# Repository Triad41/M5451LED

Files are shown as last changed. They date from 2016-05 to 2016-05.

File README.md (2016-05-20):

# M5451LED is an Arduino Shield with an 8 digit LED display and 14 additional Outputs. It is based on the M5451 40 pin Dip IC. The IC basically works as a shift register with 35 output lines. Each line can sink about 25mA which allows it to directly drive LEDs. 21 Lines are used for the display segments and digit selection in a multiplexed fashion. The additional 14 outputs are available on a 20 postion header allowing expansion of the shield. The shield uses only 2 data lines from the arduino for (clock and data). The M5451.zip file is the Arduino libaray and 2 example programs for the shield. The first is a straight loop approach for updating the display, the second is an itnerrupt based approach for updating the display.

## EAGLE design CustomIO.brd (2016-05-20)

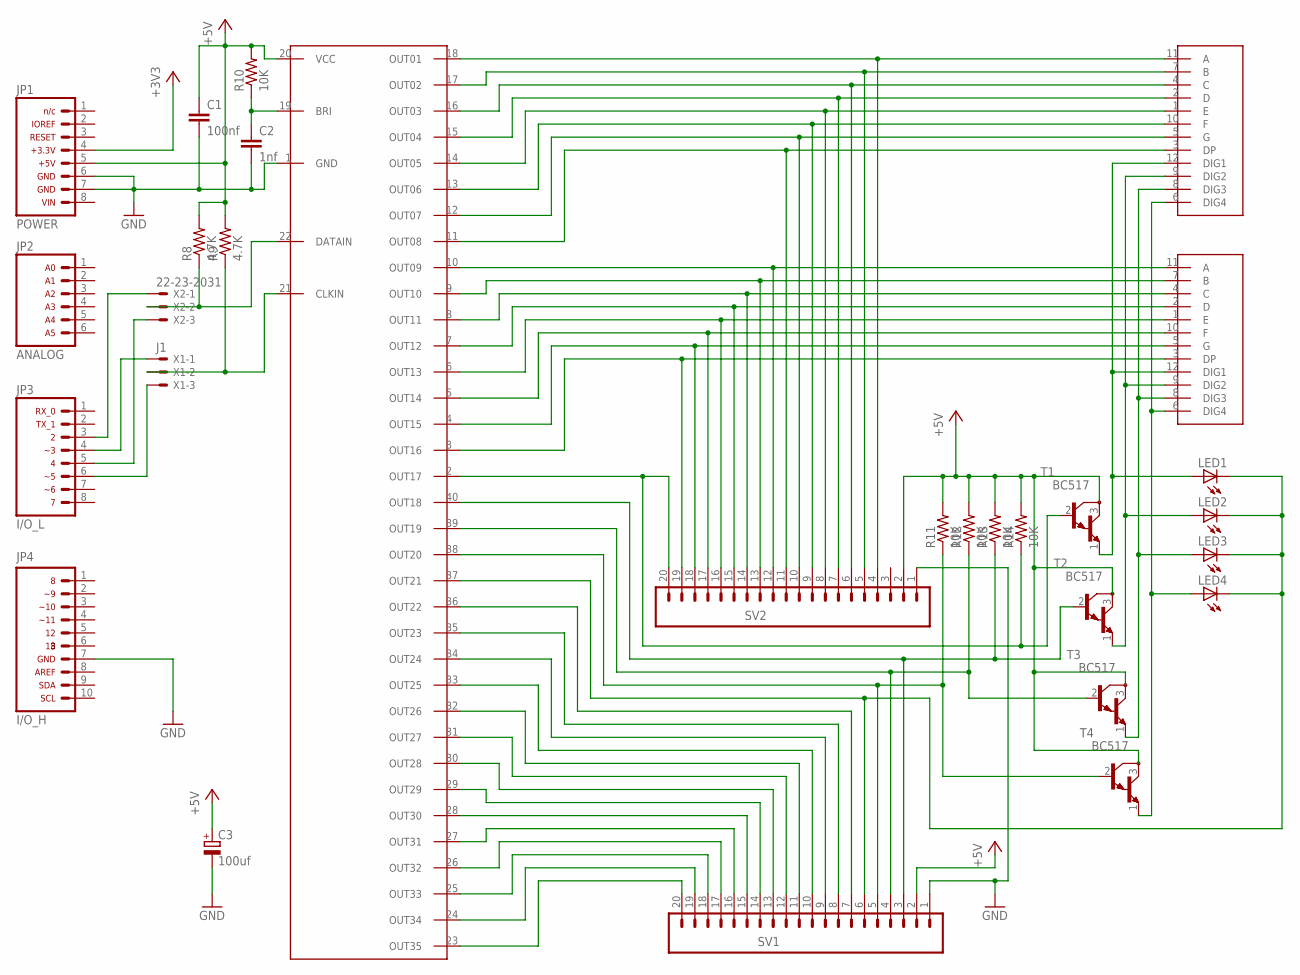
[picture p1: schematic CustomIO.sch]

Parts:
C1: 100nf; C2.5-4
C2: 1nf; C5B2.5
C3: 100uf; E2,5-7---100UF
JP1: ARDUINO_CONN-POWERSIP; CONN-1X08
JP2: ARDUINO_CONN-ANALOGSIP; CONN-1X06
JP3: ARDUINO_CONN-IO_LSIP; CONN-1X08
JP4: ARDUINO_CONN-IO_HSIP; CONN-1X10
LED1, LED2, LED3, LED4: LED3MM; HLMP-D105
R8, R9: 4.7K; AXIAL-0.3-KIT
R10, R11, R12, R13, R14: 10K; AXIAL-0.3-KIT
SV1, SV2: MA10-2
T1, T2, T3, T4: BC517; TO92
U$1: ST-M5451PDIP40; DIL40
U$2, U$3: LDS-3461BXTHURHOLE; LDS-3461BX
X1: J1; 22-23-2031
X2: 22-23-2031

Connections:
+3V3: JP1.4
+5V: C1.1, C3.+, JP1.5, R8.P$2 (2), R9.P$2 (2), R10.P$2 (2), R11.P$2 (2), R12.P$2 (2), R13.P$2 (2), R14.P$2 (2), SV1.2, SV2.2, T1.3 (C), T2.3 (C), T3.3 (C), T4.3 (C), U$1.20 (VCC)
GND: C1.2, C2.2, C3.-, JP1.6, JP1.7, JP4.7, SV1.1, SV2.1, U$1.1 (GND)
unnamed: SV2.4, U$1.18 (OUT01), U$2.11 (A)
unnamed: SV2.5, U$1.17 (OUT02), U$2.7 (B)
unnamed: SV2.6, U$1.16 (OUT03), U$2.4 (C)
unnamed: SV2.7, U$1.15 (OUT04), U$2.2 (D)
unnamed: SV2.8, U$1.14 (OUT05), U$2.1 (E)
unnamed: SV2.9, U$1.13 (OUT06), U$2.10 (F)
unnamed: SV2.10, U$1.12 (OUT07), U$2.5 (G)
unnamed: SV2.11, U$1.11 (OUT08), U$2.3 (DP)
unnamed: LED4.A, T4.1 (E), U$2.6 (DIG4), U$3.6 (DIG4)
unnamed: LED3.A, T3.1 (E), U$2.8 (DIG3), U$3.8 (DIG3)
unnamed: LED2.A, T2.1 (E), U$2.9 (DIG2), U$3.9 (DIG2)
unnamed: LED1.A, T1.1 (E), U$2.12 (DIG1), U$3.12 (DIG1)
unnamed: SV2.12, U$1.10 (OUT09), U$3.11 (A)
unnamed: SV2.13, U$1.9 (OUT10), U$3.7 (B)
unnamed: SV2.14, U$1.8 (OUT11), U$3.4 (C)
unnamed: SV2.15, U$1.7 (OUT12), U$3.2 (D)
unnamed: SV2.16, U$1.6 (OUT13), U$3.1 (E)
unnamed: SV2.17, U$1.5 (OUT14), U$3.10 (F)
unnamed: SV2.18, U$1.4 (OUT15), U$3.5 (G)
unnamed: SV2.19, U$1.3 (OUT16), U$3.3 (DP)
unnamed: SV1.20, U$1.23 (OUT35)
unnamed: SV1.19, U$1.24 (OUT34)
unnamed: SV1.18, U$1.25 (OUT33)
unnamed: SV1.17, U$1.26 (OUT32)
unnamed: SV1.16, U$1.27 (OUT31)
unnamed: SV1.15, U$1.28 (OUT30)
unnamed: SV1.14, U$1.29 (OUT29)
unnamed: SV1.13, U$1.30 (OUT28)
unnamed: SV1.12, U$1.31 (OUT27)
unnamed: SV1.11, U$1.32 (OUT26)
unnamed: SV1.10, U$1.33 (OUT25)
unnamed: SV1.9, U$1.34 (OUT24)
unnamed: SV1.8, U$1.35 (OUT23)
unnamed: SV1.7, U$1.36 (OUT22)
unnamed: LED1.K (C), LED2.K (C), LED3.K (C), LED4.K (C), SV1.6, U$1.37 (OUT21)
unnamed: R11.P$1 (1), SV1.5, T4.2 (B), U$1.38 (OUT20)
unnamed: R12.P$1 (1), SV1.4, T3.2 (B), U$1.39 (OUT19)
unnamed: R13.P$1 (1), SV1.3, T2.2 (B), U$1.40 (OUT18)
unnamed: R14.P$1 (1), SV2.20, T1.2 (B), U$1.2 (OUT17)
unnamed: R9.P$1 (1), U$1.21 (CLKIN), X1.2
unnamed: C2.1, R10.P$1 (1), U$1.19 (BRI)
unnamed: R8.P$1 (1), U$1.22 (DATAIN), X2.2
unnamed: JP3.3, X2.1
unnamed: JP3.4, X1.1
unnamed: JP3.5, X2.3
unnamed: JP3.6, X1.3

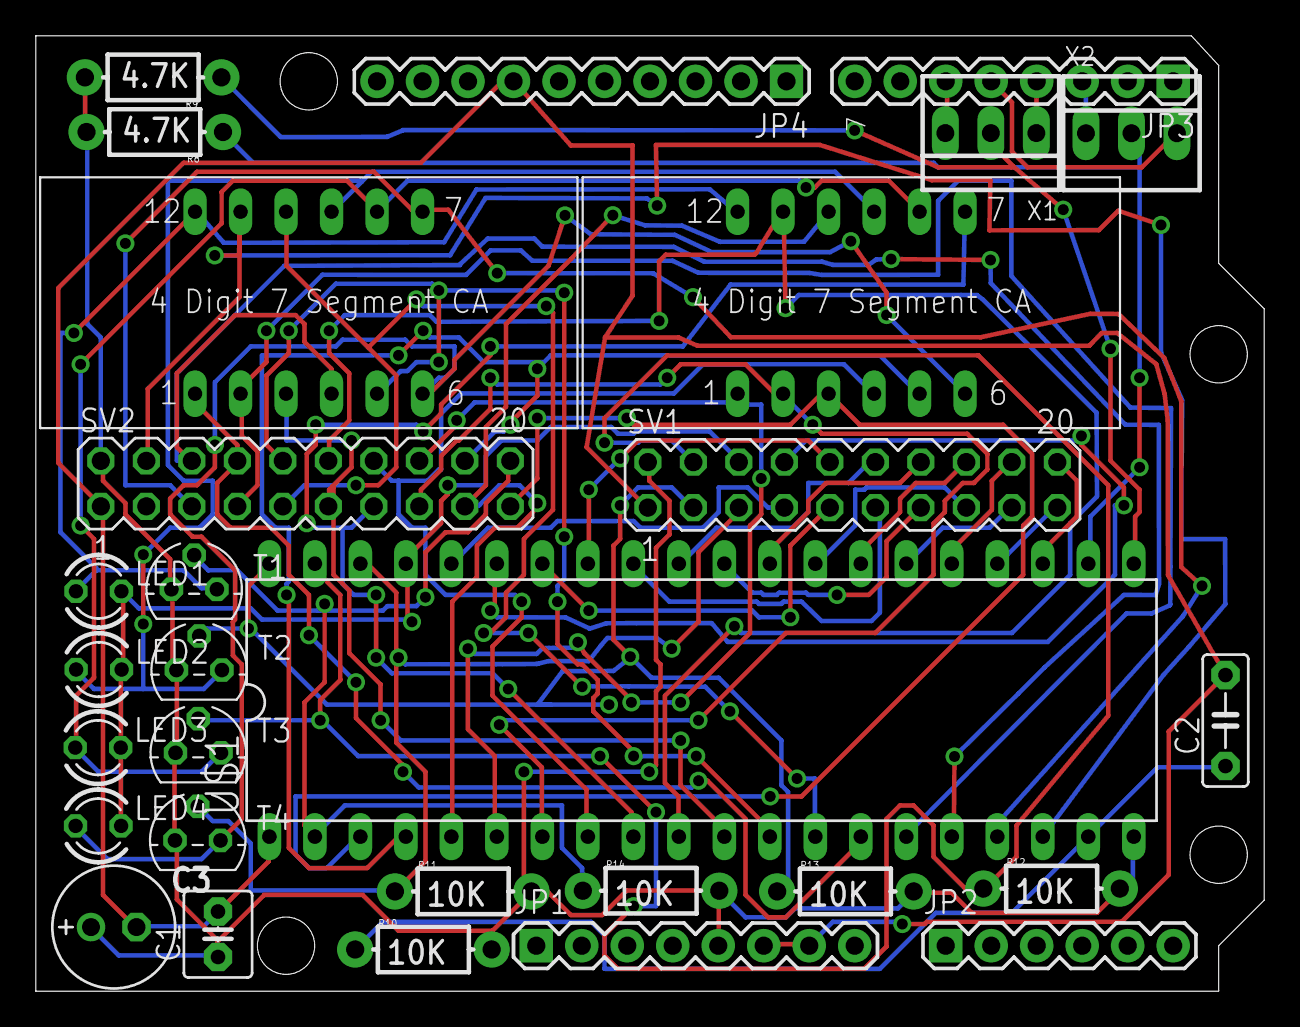
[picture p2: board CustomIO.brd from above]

Board: 2 copper layers, 68.6 x 53.3 mm, 29 parts (0 on the bottom side), 48 nets.

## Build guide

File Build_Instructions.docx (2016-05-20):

Extended I/O with 8 Digit LED Display

## Bill of Materials

C1 | 100nf (0.1 μf ) capacitor (104 marking) | 1
C2 | 1nf (0.001 μf) capacitor (102 marking) | 1
C3 | 100uf Electrolytic capacitor | 1

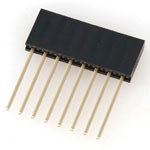
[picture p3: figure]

JP1,JP3 | 8 Position 8 x 1 .1 (2.54mm) Tall Header Arduino Connector | 2

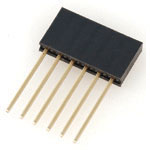
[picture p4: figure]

JP2 | 6 Position 6 x 1 .1 (2.54mm) Tall Header Arduino Connector | 1
JP4 | 10 Position 10 x 1 .1 (2.54mm) Tall Header Arduino Connector | 1

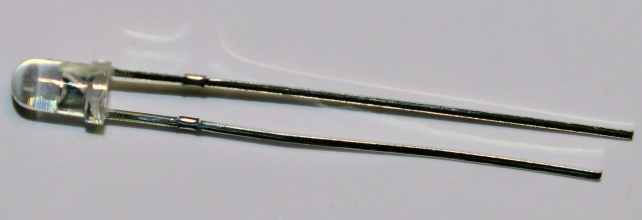
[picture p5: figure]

LED1 – LED4 | 3MM LED | 4
R8,R9 | 4.7K 1/8 W (picture for reference only) (Yellow – Violet – Red) 4 band (Yellow Violet Black Brown) 5 Band | 2
R10 – R14 | 10K 1/8 W (picture for reference only) (Brown-Black-Orange) 4 Band (Brown-Black-Black-Red)5 Band | 5
SV1-SV2 | 20 Position, 10x 2 Header | 2
T1 – T4 | 2N2907 PNP Transistor | 4
U1 | M5451 PDIP 40pin Display Controller | 1

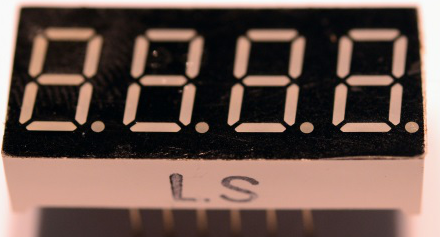
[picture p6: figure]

U2 -U3 | LDS-3461B 4 Digit 7 Segment Display | 2
X1,X2 | 3 Position x 1 Header | 2
Jumpers | 2 Position x 1 row .1 (2.54mm) Shunt | 2

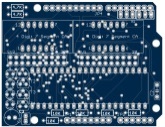
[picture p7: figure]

PCB | | 1

Schematic

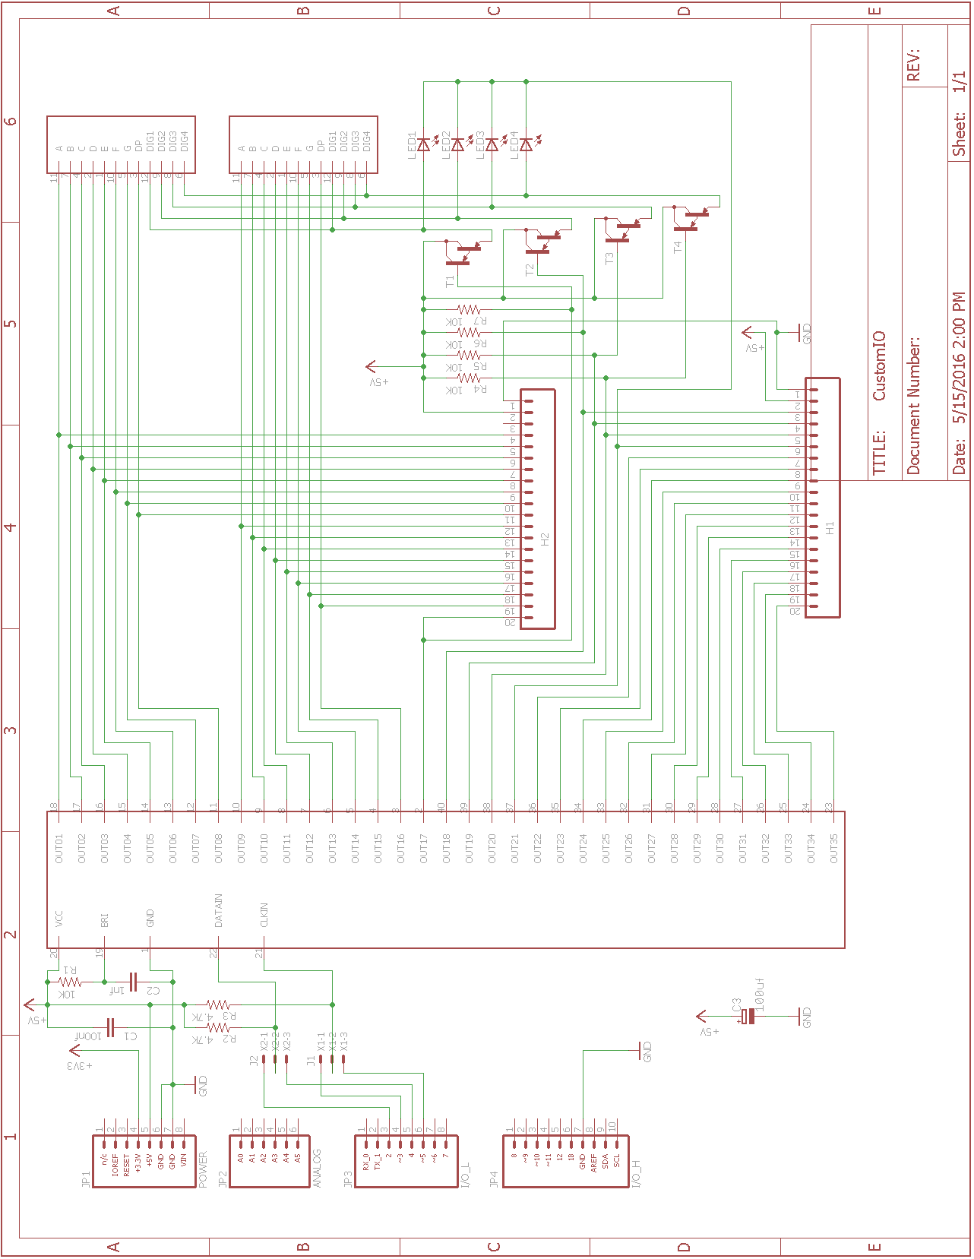
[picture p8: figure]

## Assembly

### 1 – Resistors

Solder in place the 4.7K resistors.

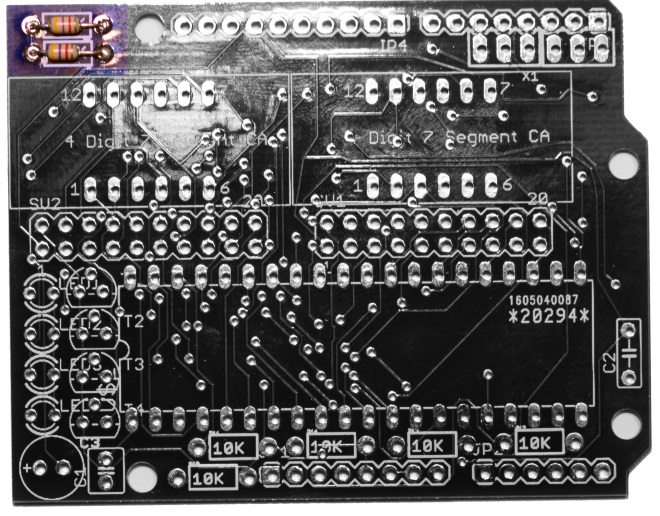
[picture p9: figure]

Solder in place the 10K resistors.

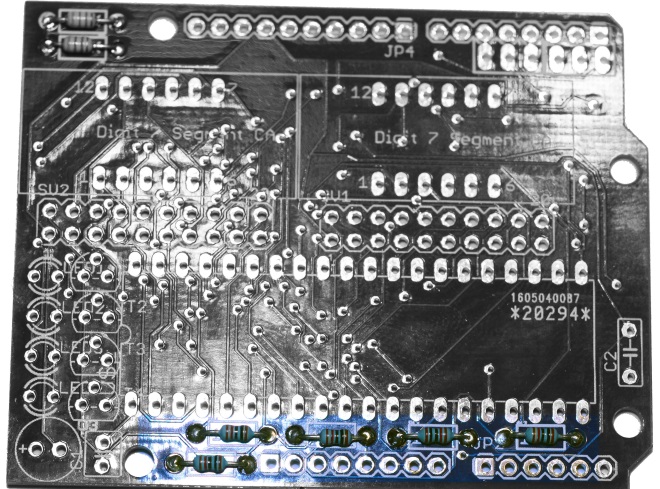
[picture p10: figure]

### 2 – Capacitors

Solder in place the 100nf (.001 μ f) Cermic Disc Capacitor.

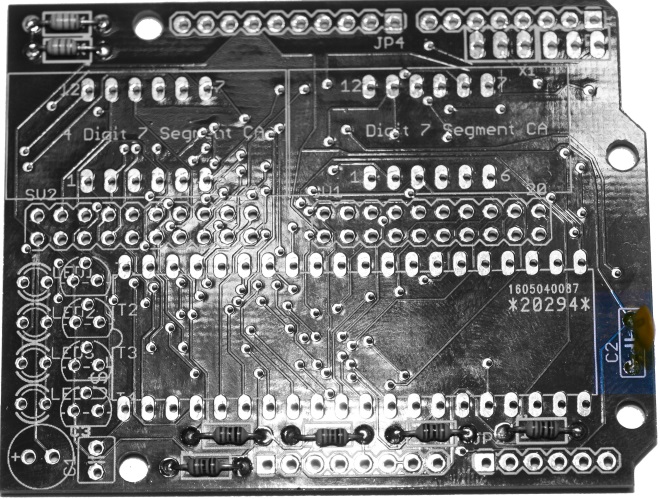
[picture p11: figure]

Solder in place the 0.1 μ f Capicator

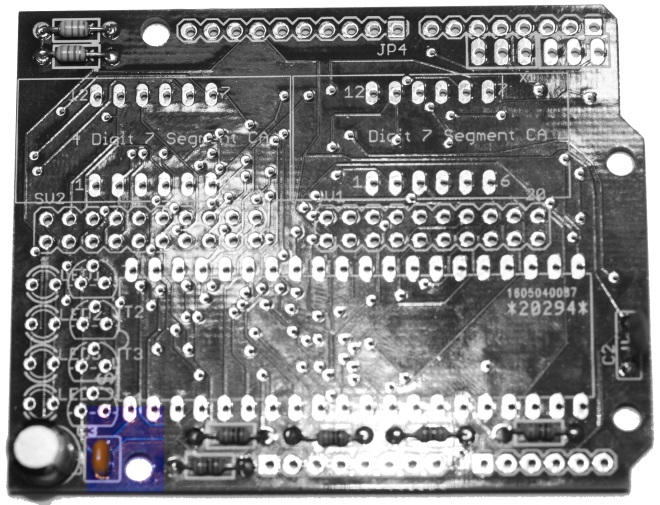
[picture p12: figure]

Solder in place the 100 μ f 6.3V Electrolytic Capacitor. It is important to note the polarity. The Capacitor is marked for the Negative lead.

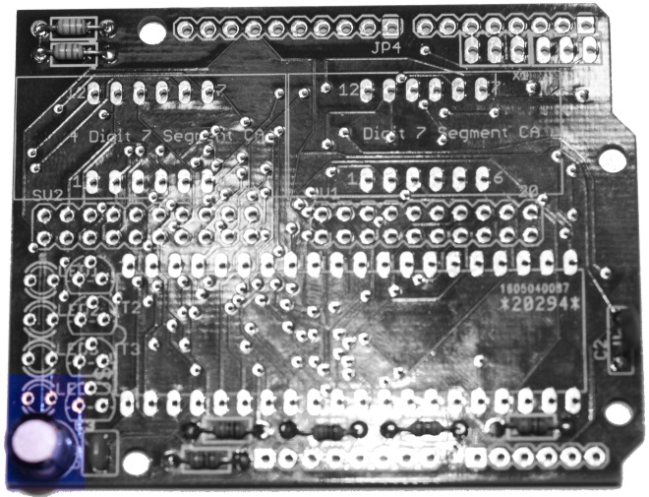
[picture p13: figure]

### 3 – Jumper and IO Headers

Solder in the 3 position by 1 row headers.

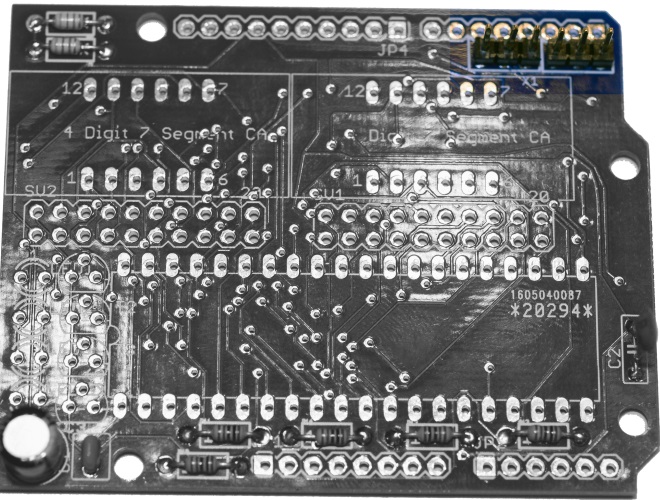
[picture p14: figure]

Solder in the 20 position (10 x2) Headers.

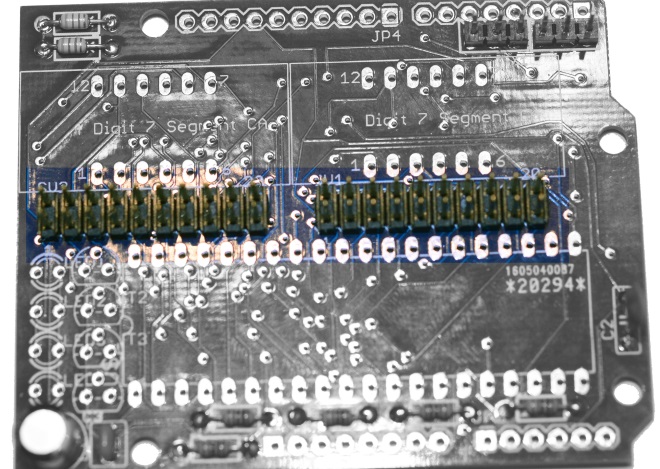
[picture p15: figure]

### 3 – LED Display and LEDS

Solder in the LED 7 Segment Displays

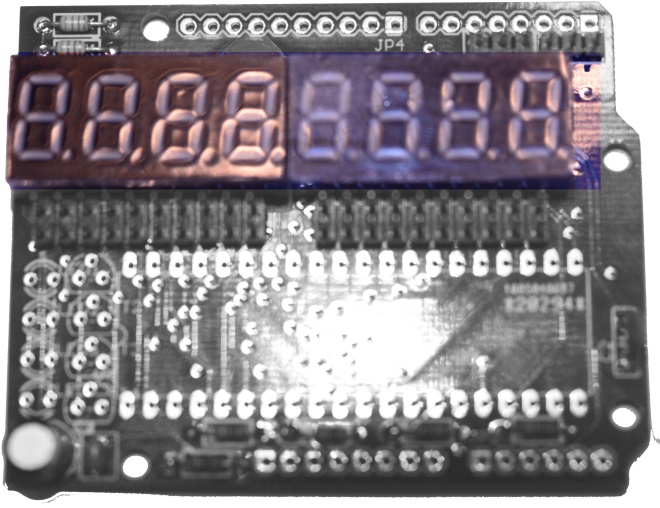
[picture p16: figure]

Solder in the LEDS. It is important to note the polarity. The Flat side is towards the middle of the board or the long lead is towards the edge of the board.

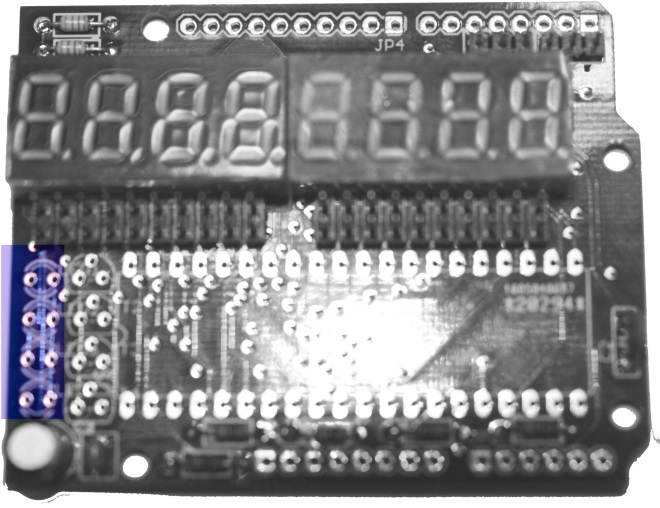
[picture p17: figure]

### 3 – Transistors

Solder in the Transistors.

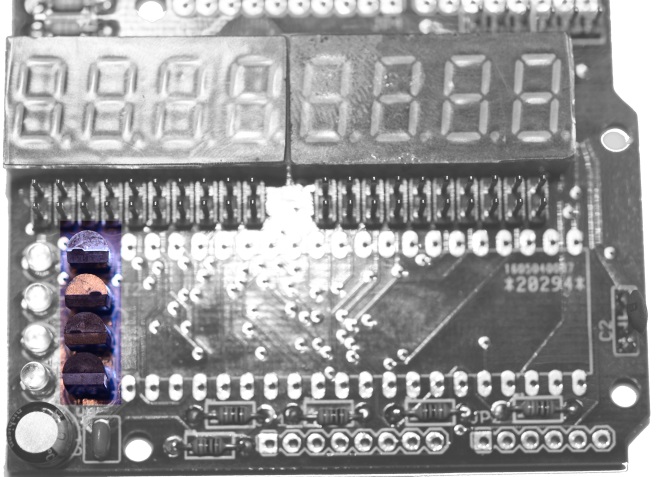
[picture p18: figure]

### 4 – IC

Solder in the IC. Pin 1 is towards the Transistors. (notch/dimple) Be careful as the pins are delicate.

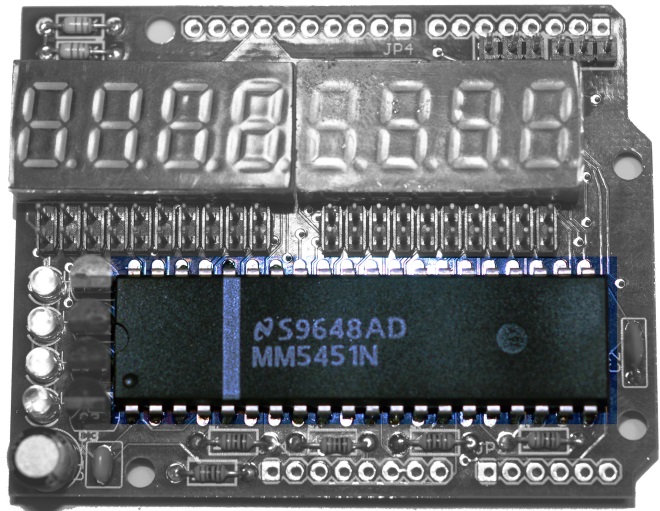
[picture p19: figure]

### 9 – Arduino Connectors

Solder in the Arduino Headers.

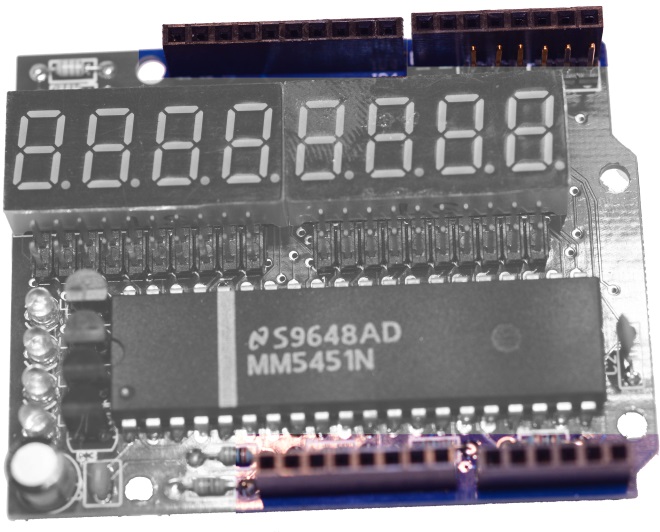
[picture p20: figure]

## Configuration

### Jumpers

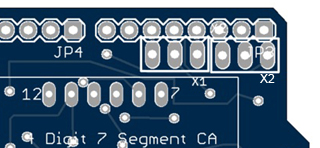
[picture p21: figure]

X1 – M5451 Clock to Arduino Data Pin Selection | Arduino Data Pin 3
X1 – M5451 Clock to Arduino Data Pin Selection | Arduino Data Pin 5
X2 – M5451 Data to Arduino Data Pin Selection | Arduino Data Pin 4
X2 – M5451 Data to Arduino Data Pin Selection | Arduino Data Pin 2

Note – For running the Sample Programs, set the Jumpers for Arduino Pins 2 and 3.

## Testing

### Sample Code

A Library is available on . It includes two example programs.

The First Example demonstrates working with the shield to update the display within the Main loop on an Arduino Sketch.

#include <M5451LED.h>

//clock pin is jumper selectable between 3 or 5

int myClockPin = 3; // Arduino pin that goes to M5451 clock

//data pin is jumper selectable between 2 or 4

int mySerDataPin = 2; // Arduino pin that goes to M5451 data

M5451 board(myClockPin,mySerDataPin);

void UpdateDisplay()

{

unsigned long int j;

for(byte dig = 0; dig < 4; dig++)

{

j = 0x00010000;

j = j << dig; //set the set of digits

j = j | ((unsigned long int)board.digitCodes[dig+4]) << 8; //shift digit segments into position

j = j | board.digitCodes[dig]; //or in other digit segments

board.setiopins(j,board.ExtendedIOPins); //load the shift register

//delay(10);

}

}

void loop() // run over and over again

{

//Sample code

//negative number check //or read a value, temp, sensor etc. upyo you

board.setNumber(102499,2);

for(int c = 0; c < 4000; c++)

{

UpdateDisplay();

}

board.BlankDisplay();

board.setNumber(-2499,2);

for(int c = 0; c < 4000; c++)

{

UpdateDisplay();

}

board.BlankDisplay();

board.setNumber(100000,2);

for(int c = 0; c < 4000; c++)

{

UpdateDisplay();

}

board.BlankDisplay();

byte dp = 0;

// count up to 499

// deminstrates changing the displayed value which is

// then displayed by the Interrupt service routine

for (unsigned long int cnt=0;cnt < 500;cnt++)

{

board.ExtendedIOPins = board.ExtendedIOPins << 1;

if ((board.ExtendedIOPins == 0x0000)||(board.ExtendedIOPins == 0x8000))

{

board.ExtendedIOPins = 0x0001;

}

board.setNumber(cnt,0); //cnt, decimal places

for(int c = 0; c < 250; c++)

{

UpdateDisplay();

}

}

//End Sample Code

//more code goes here...

}

//runs a circle around each digit (segments a,b,c,d,e,f)

//an extended IO pin is held constant while each segment is is toggled

//deminstrates segments and extended I/O updated at different timings

//the timer interrupt must be disabled while running loops

void littlechaser()

{

unsigned long int val;

board.ExtendedIOPins = 0x0001;

for(byte y = 0; y <15; y++) // outer loop is when the extended IO is updated

{

val = 0x000F0101; //All Digits ON, start with segment a

for(byte segs = 0; segs < 6; segs ++) //inner loop is when the segments are updated

{

board.setiopins(val,board.ExtendedIOPins);

val = val<<1L;

val = val & 0x0000FFFF; //keep segments

val = val | 0x000F0000; //all digits on

delay(75);

}

board.ExtendedIOPins = board.ExtendedIOPins << 1;

}

}

//runs a circle around all the digits

//extended IO pins are changed with each segment

//the timer interrupt must be disabled while running chaser

void bigchaser()

{

static const unsigned int ExtIOPattern[] = { 0xAAAA, 0x5555 };

static const unsigned int long bigchaserMap[] = {

0x00010001, // 000 00000000 00000001 00000000 00000001 // digit 1 segment a

0x00010020, // 000 00000000 00000001 00000000 00100000 // digit 1 segment f

0x00010010, // 000 00000000 00000001 00000000 00010000 // digit 1 segment e

0x00010008, // 000 00000000 00000001 00000000 00001000 // digit 1 segment d

0x00020008, // 000 00000000 00000010 00000000 00001000 // digit 2 segment d

0x00040008, // 000 00000000 00000100 00000000 00001000 // digit 3 segment d

0x00080008, // 000 00000000 00001000 00000000 00001000 // digit 4 segment d

0x00010800, // 000 00000000 00000001 00001000 00000000 // digit 5 segment d

0x00020800, // 000 00000000 00000010 00001000 00000000 // digit 6 segment d

0x00040800, // 000 00000000 00000100 00001000 00000000 // digit 7 segment d

0x00080800, // 000 00000000 00001000 00001000 00000000 // digit 8 segment d

0x00080400, // 000 00000000 00001000 00000100 00000000 // digit 8 segment c

0x00080200, // 000 00000000 00001000 00000010 00000000 // digit 8 segment b

0x00080100, // 000 00000000 00001000 00000001 00000000 // digit 8 segment a

0x00040100, // 000 00000000 00000100 00000001 00000000 // digit 7 segment a

0x00020100, // 000 00000000 00000010 00000001 00000000 // dugit 6 segment a

0x00010100, // 000 00000000 00000001 00000001 00000000 // digit 5 segment a

0x00080001, // 000 00000000 00001000 00000000 00000001 // digit 4 segment a

0x00040001, // 000 00000000 00000100 00000000 00000001 // dugit 3 segment a

0x00020001};// 000 00000000 00000010 00000000 00000001 // digit 2 segment a

byte co, c = 0;

for (co=0;co < 6;co++)

{

for(c = 0; c< 20;c++)

{

board.setiopins(bigchaserMap[c],ExtIOPattern[c & 0x01]);

delay(75);

}

}

for (co=0;co < 6;co++)

{

for(c = 20; c>0;c--)

{

board.setiopins(bigchaserMap[c-1],ExtIOPattern[(c-1) & 0x01]);

delay(75);

}

}

}

void chkLEDS()

{

unsigned long int j;

for (byte c = 0; c < 5; c++)

{

j = 0x00110000;

board.setiopins(j,0);

delay(75);

j = 0x00120000;

board.setiopins(j,0);

delay(75);

j = 0x00140000;

board.setiopins(j,0);

delay(75);

j = 0x00180000;

board.setiopins(j,0);

delay(75);

}

}

void setup() // run once, when the sketch starts

{

littlechaser();

bigchaser();

chkLEDS();

}

The second example demonstrates using an Interrupt Service Routine to update the display.

#include <TimerOne.h>

#include <M5451LED.h>

//clock pin is jumper selectable between 3 or 5

int myClockPin = 3; // Arduino pin that goes to M5451 clock

//data pin is jumper selectable between 2 or 4

int mySerDataPin = 2; // Arduino pin that goes to M5451 data

M5451 board(myClockPin,mySerDataPin);

// Every 20mS the values in the DigitCodes array and

// The values in the ExtendedIPPins are written out

void timerIsr()

{

unsigned long int j;

for(byte dig = 0; dig < 4; dig++)

{

j = 0x00010000;

j = j << dig; //set the set of digits

j = j | ((unsigned long int)board.digitCodes[dig+4]) << 8; //shift digit segments into position

j = j | board.digitCodes[dig]; //or in other digit segments

board.setiopins(j,board.ExtendedIOPins); //load the shift register

//delay(10);

}

}

void loop() // run over and over again

{

//Sample code

//negative number check

board.setNumber(102499,2);

delay(750);

board.setNumber(-2499,2);

delay(750);

board.setNumber(100000,2);

delay(750);

board.BlankDisplay();

delay(1);

byte dp = 0;

// count up to 499

// deminstrates changing the displayed value which is

// then displayed by the Interrupt service routine

for (unsigned long int cnt=0;cnt < 500;cnt++)

{

board.ExtendedIOPins = board.ExtendedIOPins << 1;

if ((board.ExtendedIOPins == 0x0000)||(board.ExtendedIOPins == 0x8000))

{

board.ExtendedIOPins = 0x0001;

}

board.setNumber(cnt,0); //cnt, decimal places

delay(150);

}

//End Sample Code

//more code goes here...

}

//runs a circle around each digit (segments a,b,c,d,e,f)

//an extended IO pin is held constant while each segment is is toggled

//deminstrates segments and extended I/O updated at different timings

void littlechaser()

{

unsigned long int val;

board.ExtendedIOPins = 0x0001;

for(byte y = 0; y <15; y++) // outer loop is when the extended IO is updated

{

val = 0x000F0101; //All Digits ON, start with segment a

for(byte segs = 0; segs < 6; segs ++) //inner loop is when the segments are updated

{

board.setiopins(val,board.ExtendedIOPins);

val = val<<1L;

val = val & 0x0000FFFF; //keep segments

val = val | 0x000F0000; //all digits on

delay(75);

}

board.ExtendedIOPins = board.ExtendedIOPins << 1;

}

}

//runs a circle around all the digits

//extended IO pins are changed with each segment

void bigchaser()

{

static const unsigned int ExtIOPattern[] = { 0xAAAA, 0x5555 };

static const unsigned int long bigchaserMap[] = {

0x00010001, // 000 00000000 00000001 00000000 00000001 // digit 1 segment a

0x00010020, // 000 00000000 00000001 00000000 00100000 // digit 1 segment f

0x00010010, // 000 00000000 00000001 00000000 00010000 // digit 1 segment e

0x00010008, // 000 00000000 00000001 00000000 00001000 // digit 1 segment d

0x00020008, // 000 00000000 00000010 00000000 00001000 // digit 2 segment d

0x00040008, // 000 00000000 00000100 00000000 00001000 // digit 3 segment d

0x00080008, // 000 00000000 00001000 00000000 00001000 // digit 4 segment d

0x00010800, // 000 00000000 00000001 00001000 00000000 // digit 5 segment d

0x00020800, // 000 00000000 00000010 00001000 00000000 // digit 6 segment d

0x00040800, // 000 00000000 00000100 00001000 00000000 // digit 7 segment d

0x00080800, // 000 00000000 00001000 00001000 00000000 // digit 8 segment d

0x00080400, // 000 00000000 00001000 00000100 00000000 // digit 8 segment c

0x00080200, // 000 00000000 00001000 00000010 00000000 // digit 8 segment b

0x00080100, // 000 00000000 00001000 00000001 00000000 // digit 8 segment a

0x00040100, // 000 00000000 00000100 00000001 00000000 // digit 7 segment a

0x00020100, // 000 00000000 00000010 00000001 00000000 // dugit 6 segment a

0x00010100, // 000 00000000 00000001 00000001 00000000 // digit 5 segment a

0x00080001, // 000 00000000 00001000 00000000 00000001 // digit 4 segment a

0x00040001, // 000 00000000 00000100 00000000 00000001 // dugit 3 segment a

0x00020001};// 000 00000000 00000010 00000000 00000001 // digit 2 segment a

byte co, c = 0;

for (co=0;co < 6;co++)

{

for(c = 0; c< 20;c++)

{

board.setiopins(bigchaserMap[c],ExtIOPattern[c & 0x01]);

delay(75);

}

}

for (co=0;co < 6;co++)

{

for(c = 20; c>0;c--)

{

board.setiopins(bigchaserMap[c-1],ExtIOPattern[(c-1) & 0x01]);

delay(75);

}

}

}

void chkLEDS()

{

unsigned long int j;

for (byte c = 0; c < 5; c++)

{

j = 0x00110000;

board.setiopins(j,0);

delay(75);

j = 0x00120000;

board.setiopins(j,0);

delay(75);

j = 0x00140000;

board.setiopins(j,0);

delay(75);

j = 0x00180000;

board.setiopins(j,0);

delay(75);

}

}

void setup() // run once, when the sketch starts

{

littlechaser();

bigchaser();

chkLEDS();

Timer1.initialize(300); //play with this value for more or less updates

Timer1.attachInterrupt( timerIsr );

}

Video’s of the running examples can be found at

https://youtu.be/1ersXG6CpGg

and

https://youtu.be/Mj3757OHWhI

### M5451LED Library

The library serves two main purposes.

- It contains the Code to shift out the data to the M5451 Chip.
- It contains the Code to convert a given number into the data needed to display the correct segments on the display.

## Programming

### I/O information

The M5451 has 35 I/O Lines, within the sample program they are mapped into an unsigned Long int and an unsigned int. This allows separate control of the display and the extended I/O.

Unsigned Long int

0000 0000 0000 0000 0000 0000 0000 0000

|||| |||| |||| |||| |||| |||| |||| |||--> Segment A 1 Output 1(pin 18)

|||| |||| |||| |||| |||| |||| |||| ||---> Segment B 1 Output 2(pin 17)

|||| |||| |||| |||| |||| |||| |||| |----> Segment C 1 Output 3(pin 16)

|||| |||| |||| |||| |||| |||| |||| -----> Segment D 1 Output 4(pin 15)

|||| |||| |||| |||| |||| |||| |||-------> Segment E 1 Output 5(pin 14)

|||| |||| |||| |||| |||| |||| ||--------> Segment F 1 Output 6(pin 13)

|||| |||| |||| |||| |||| |||| |---------> Segment G 1 Output 7(pin 12)

|||| |||| |||| |||| |||| |||| ----------> DP 1 Output 8(pin 11)

|||| |||| |||| |||| |||| |||------------> Segment A 2 Output 9(pin 10)

|||| |||| |||| |||| |||| ||-------------> Segment B 2 Output 10(pin 9)

|||| |||| |||| |||| |||| |--------------> Segment C 2 Output 11(pin 8)

|||| |||| |||| |||| |||| ---------------> Segment D 2 Output 12(pin 7)

|||| |||| |||| |||| |||-----------------> Segment E 2 Output 13(pin 6)

|||| |||| |||| |||| ||------------------> Segment F 2 Output 14(pin 5)

|||| |||| |||| |||| |-------------------> Segment G 2 Output 15(pin 4)

|||| |||| |||| |||| --------------------> DP 2 Output 16(pin 3)

|||| |||| |||| |||----------------------> Digit 1 Output 17 (pin 2)

|||| |||| |||| ||-----------------------> Digit 2 Output 18 (pin 40)

|||| |||| |||| |------------------------> Digit 3 Output 19 (pin 39)

|||| |||| |||| -------------------------> Digit 4 Output 20 (pin 38)

|||| |||| |||---------------------------> LED Enable Out 21 (pin 37)

------------------------- --------------> Not Used

Unsigned int

0000 0000 0000 0000

|||| |||| |||| |||---> Output 22 (pin 36)

|||| |||| |||| ||----> Output 23 (pin 35)

|||| |||| |||| |-----> Output 24 (pin 34)

|||| |||| ||||-------> Output 25 (pin 33)

|||| |||| |||--------> Output 26 (pin 32)

|||| |||| ||---------> Output 27 (pin 31)

|||| |||| |----------> Output 28 (pin 30)

|||| |||| -----------> Output 29 (pin 29)

|||| |||-------------> Output 30 (pin 28)

|||| ||--------------> Output 31 (pin 27)

|||| |---------------> Output 32 (pin 26)

|||| ----------------> Output 33 (pin 25)

|||------------------> Output 34 (pin 24)

||-------------------> Output 35 (pin 23)

---------------------> Not Used

## Pin Outs

### Exrentded I/O

Headers on the shield make available all of the I/O lines from the M5451. Lines which are used on the shield are identified in parentheses following the M5451 output name. (Note. This is the output, not the M5451 actual Pin)

Header One

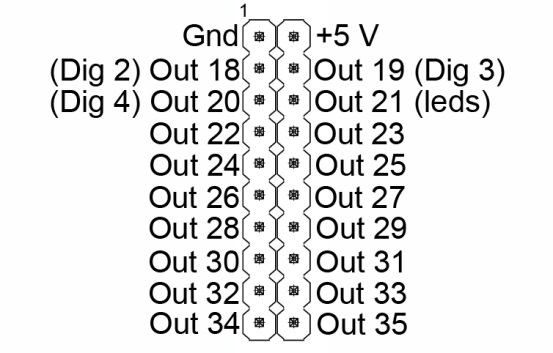
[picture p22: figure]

Header Two

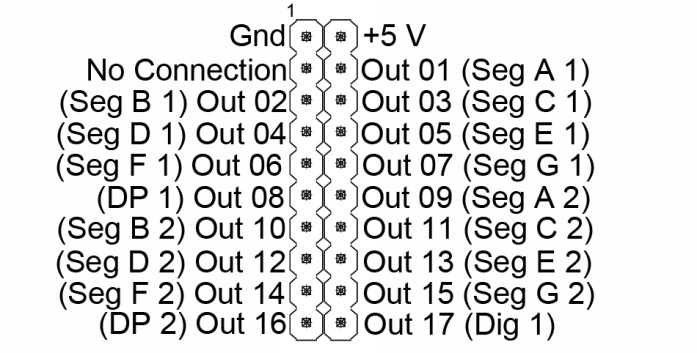
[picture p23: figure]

### Hardware Extension

Outputs from the M5451 will sink about 25mA, so transistors should be used for external control of loads such as relays or motors.

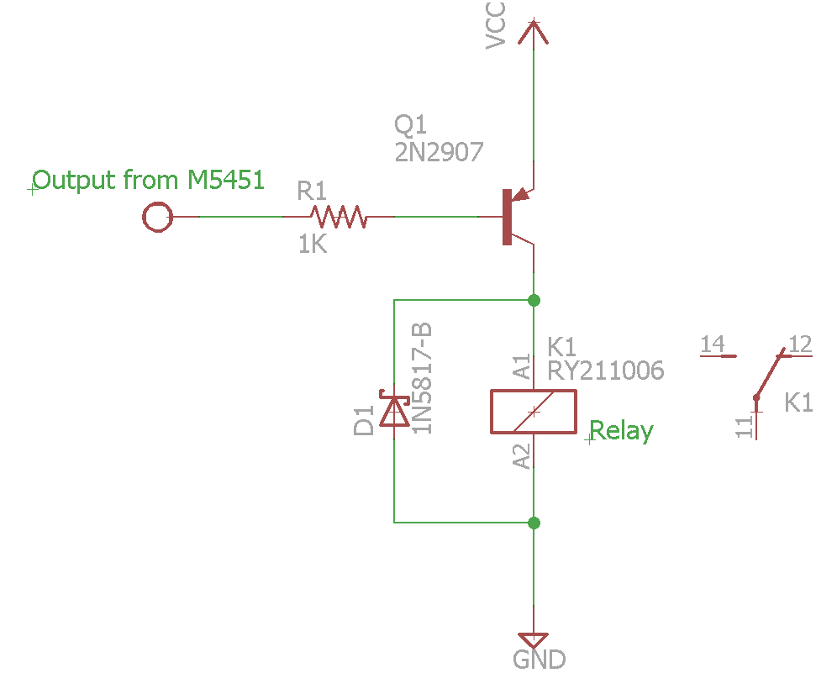
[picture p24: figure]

### M5451

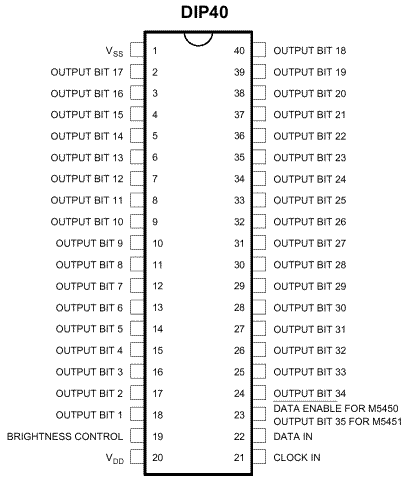
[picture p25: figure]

### 7 Segment Display

Common Anode

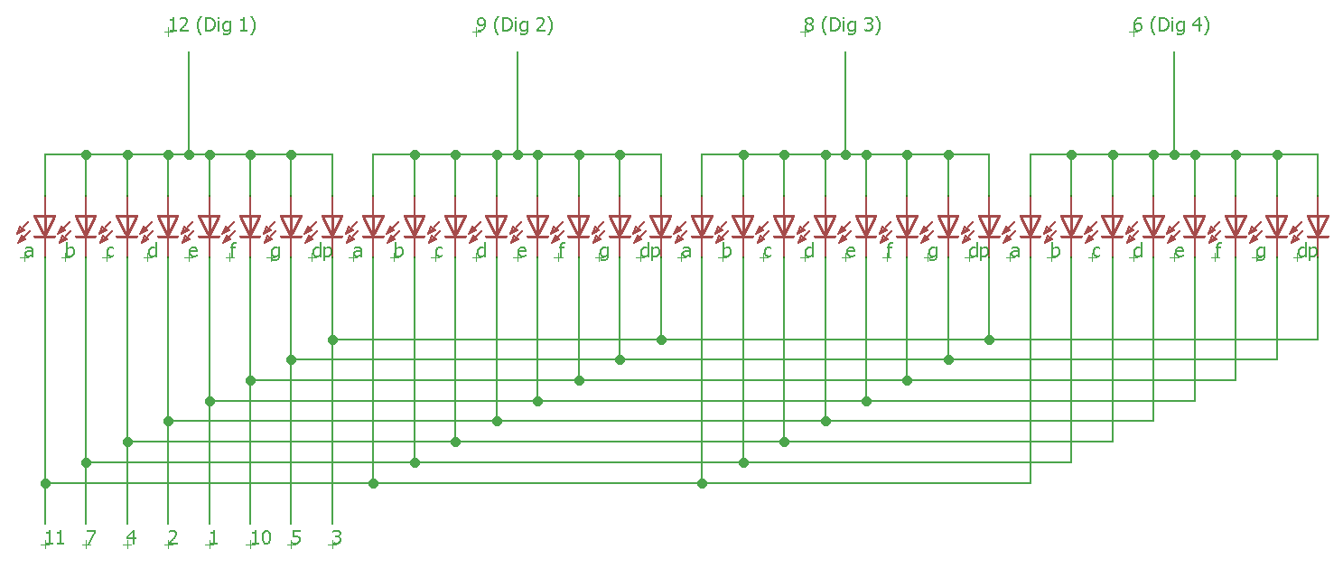
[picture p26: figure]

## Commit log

2016-05-20 M5451LED Board
    M5451LED Board
    [CustomIO.brd]
2016-05-20 M5451LED Schematic
    M5451LED Schematic
    [CustomIO.sch]
2016-05-20 Video of Sample Code Running
    Video of the sample arduino program running on the board. also available on You Tube at
    https://youtu.be/1ersXG6CpGg
    and
    https://youtu.be/Mj3757OHWhI
2016-05-20 PCB Build Instructions
    PCB Build Instructions
2016-05-20 Video of the M5451LED Shield running the sample sketch.
    Video of the M5451LED Shield running the sample sketch.
2016-05-20 Video of the M5451LED Shield running the sample sketch with some extended outputs hooked up.
    Video of the M5451LED Shield running the sample sketch with some extended outputs hooked up.

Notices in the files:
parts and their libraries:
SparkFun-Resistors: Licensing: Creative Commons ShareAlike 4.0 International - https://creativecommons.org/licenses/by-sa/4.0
